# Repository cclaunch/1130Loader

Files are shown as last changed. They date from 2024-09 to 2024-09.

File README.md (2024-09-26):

# 1130Loader

This is a minor enhancement to an IBM 1130 that allows users to enter commands from a PC either directly or through a file, entering data words into core. This will be version 5 of the design, a significant change. 

Manually toggling in programs is a time consuming affair, flipping the 16 Console Entry Switches and pushing the Program Start button to enter each word sequentially. Every change in the area of core to be loaded requires that the address be set in those entry switches and the Load IAR button be pressed.

This device utilizes the cycle steal capability of the 1130, where peripheral controllers can read or write locations in memory by causing the CPU to pause while a memory cycle is used for the peripheral, then the CPU instruction processing continues. This is very similar to DMA on a microprocessor. 

When used with a terminal program that will send lines of a text file when it receives the prompt character from the loader, this allows files to be prepared to load into core of the 1130 in a rapid and reliable way. The format of the text file was chosen to match the simh based IBM 1130 Simulator memory dump format, thus programs can be tested on the simulator, dumped to files and loaded onto the physical 1130 system for execution. The format is to place each word as four ASCII characters represening the four hex digits. If the four digit line is prefixed by the command character @, the value is loaded into the 1130 IAR to set the location for subsequent memory words. If the line is prefixed by the command character Z it loads words of 0000 into as many locations as the four hex digits specify. If the command character prefix is =, the four digit value is saved and at the end of the loading, the IAR will be set to this value as the starting point for execution. Finally the command character # entered on a line by itself will toggle the loader to activation or deactivate it. Thus each simulator memory dump file needs to have a # line added at the front and at the end. 

To use the loader, connect a serial connection to the USB connector on the 1130 and open the terminal program. The 1130 must be stopped for this to runction, otherwise nothing special is needed. 

Physically the loader consists of an Arduino Mega 2560 and a custom shield that interfaces it to the IBM 1130. This is mounted on the logic gate B, connected to header boards on the gate which are then connected to individual backplane (board) pins using wirewrap. 

The code allows you to substitute different command characters and change the prompt character.

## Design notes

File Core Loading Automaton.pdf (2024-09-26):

# Core Loading Automaton

1 | Version 4

A tool I originally developed at the request of Peter Vaughan of The National Museum of Computing, this minor modification to an IBM 1130 will allow a PC based file of memory words to be loaded automatically into the core of an 1130.

A significant speedup was accomplished over previous versions by redesigning to use the cycle steal mechanism of the IBM 1130, analogous to Direct Memory Access (DMA) of microprocessor systems. This supported higher speed peripherals which used cycle stealing to fetch or store words into core memory without involving programs running on the CPU.

The device controller requests use of cycle stealing by raising the request line for the CS level it was assigned. When the CPU has finished a memory cycle, it grants the highest priority request a cycle steal and signals it was granted by raising the CS Level line.

The controller sets the bits of the data word and the memory address by pulling down the bits of the IO Data and Address bus to zero for each bit that has a 1 value. When the cycle steal clock reaches state X6, the request is dropped and the IO Data and Address lines are turned off by the controller. The end of the cycle steal is indicated by the dropping of the CS Level line.

My device is implemented as a shield sitting on an Arduino Mega 2560 to handle the conversation with a terminal or other program outside the IBM 1130. It watches the key CPU signals and sets the data, address and cycle steal request lines just as a device controller would do. Thus, it will trigger a cycle steal for a specific core address and store a given word there.

To simplify the design, it requires that the CPU be stopped before it will work. This ensures that no device controller is attempting cycle steals and that no other requests for memory access are taking place. It uses the highest priority cycle steal level (CS Level 0).

Sending a line over the serial line starting with # indicates the start of a session. The loader will ignore input until activated. Sending another # will end the session and inform the operator to resume normal 1130 operations. If core contents are saved from the IBM 1130 simulator, that file needs to have a line with # added at the front and bottom in order to use it with the loader.

When an address (hex word prefixed by @) is received, it sets up that address in the Arduino as the location for the next data word received When it receives a hex word without the prefix, it uses the saved address in the Arduino to load the data and increments the address afterwards so that the next data word goes into the next sequential location.

When an address prefixed by = is received, the code saves that address and then when the session is deactivated, it will remind the user to load that into the IAR so that the 1130 will fetch instructions from that address when Prog Start is pushed.

If a hex word is prefixed by Z then the hex value is a count for how many words of 0000 should be loaded into contiguous locations in 1130 core.

The loader communicates over a serial link on a USB cable, interpreting each line of text sent to it as four hex characters with some simple error checking. The line is converted to the 16 bit values for the data word to load.

The device uses open collector gates to connect selected pins on the 1130 to ground when that signal is asserted by the logic. Gates are connected to pins where we need to read CPU signals, passing them to the logic. Wire wrap is used to link the pins to a header on the shield.

We connect to the +12V power supply from the main 1130 distribution terminal block and use it to provide power to our loader device. The components on the shield regulates the raw supply down to 9V for powering the Arduino and to 5V to power the logic on the shield.

Software

The Arduino program loops listening to the serial port (USB link to PC) at 9600-N-8-1 setting. Command characters (#, =, @, or Z) are pulled off the line and handled first. It builds up a line of four characters, if longer it is an error and if shorter the input is ignored. The code skips any NL (x0A) or CR (x0D). It looks for exactly four characters that are valid hexadecimal - 0, 1, 2, 3, 4, 5, 6, 7, 8, 9, A, B, C, D, E, or F. The letters can be upper or lower case ASCII.

Once it has a good word, it sets the data value and address on its output pins and raises the request line to the shield via another output pin. It waits for the incoming Request Done signal on an input pin, then drops the data, address and request lines to end this cycle. Once it is done, we go back to give a prompt and accept the next word of entry from the terminal hooked to our USB cable. We also bump the saved memory address at the end of each cycle.

If the user enters an @ in the line with the four hex characters, we capture that as the new memory address we will output for the next data request.

This code is written for an Arduino Mega 2560 board. We need 32 output pins and 1 input pin, which excludes most of the smaller Arduino boards. The hardware that interfaces this to the IBM 1130 is contained on a shield, a small PCB that is mounted atop the Arduino.

The code and other design files is shared on Github to be available to any 1130 restorer wishing to use or modify this device.

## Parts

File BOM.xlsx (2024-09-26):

Part number | Value | Size | Vendor | vendor number
U1 | 74LS74 | 14SOIC | Digikey | 296-14899-1-ND
U2 | 74LS00 | 14SOIC | Digikey | 296-14873-1-ND
U3 | LM78L05 | S08 | Mouser | 926-LM78L05ACMX/NOPB
U6 | 74LS04 | 14SOIC | Digikey | 296-14875-1-ND
U7 | 74LS07 | 14SOIC | Digikey | 296-14877-1-ND
U8 | 74LS03 | 14SOIC | Digikey | 296-33951-5-ND
U9 | 74LS03 | 14SOIC | Digikey | 296-33951-5-ND
U10 | 74LS03 | 14SOIC | Digikey | 296-33951-5-ND
U11 | 74LS03 | 14SOIC | Digikey | 296-33951-5-ND
U12 | 74LS03 | 14SOIC | Digikey | 296-33951-5-ND
U13 | 74LS03 | 14SOIC | Digikey | 296-33951-5-ND
U14 | 74LS03 | 14SOIC | Digikey | 296-33951-5-ND
U15 | 74LS03 | 14SOIC | Digikey | 296-33951-5-ND
U17 | LM78L12 | S08 | Digikey | 296-LM78L12ACMX/NOPBCT-ND
U19 | 74LS04 | 14SOIC | Digikey | 296-14875-1-ND
U20 | 74LS74 | 14SOIC | Digikey | 296-14899-1-ND
R1 | 5K | 0805 | Digikey | 541-CRCW08055K00JNTACT-ND
R2 | 5K | 0805 | Digikey | 541-CRCW08055K00JNTACT-ND
R3 | 5K | 0805 | Digikey | 541-CRCW08055K00JNTACT-ND
J1 | 1x8 | 2.54mm | Digikey | 2057-PH1-08-UA-ND
J2 | 1x16 | 2.54mm | Digikey | 2057-PH1-16-UA-ND
J3 | 1x16 | 2.54mm | Digikey | 2057-PH1-16-UA-ND
J4 | 1x2 |  | Digikey | 277-1236-ND
C1 | 100nf | 0805 | Digikey | 478-KGM21NR71H104KTCT-ND
C2 | 100nf | 0805 | Digikey | 478-KGM21NR71H104KTCT-ND
C3 | 100nf | 0805 | Digikey | 478-KGM21NR71H104KTCT-ND
C4 | 100nf | 0805 | Digikey | 478-KGM21NR71H104KTCT-ND
C5 | 100nf | 0805 | Digikey | 478-KGM21NR71H104KTCT-ND
C6 | 100nf | 0805 | Digikey | 478-KGM21NR71H104KTCT-ND
C7 | 100nf | 0805 | Digikey | 478-KGM21NR71H104KTCT-ND
C8 | 100nf | 0805 | Digikey | 478-KGM21NR71H104KTCT-ND
C9 | 100nf | 0805 | Digikey | 478-KGM21NR71H104KTCT-ND
C11 | 100nf | 0805 | Digikey | 478-KGM21NR71H104KTCT-ND
C12 | 100nf | 0805 | Digikey | 478-KGM21NR71H104KTCT-ND
C13 | 100nf | 0805 | Digikey | 478-KGM21NR71H104KTCT-ND
C14 | 100nf | 0805 | Digikey | 478-KGM21NR71H104KTCT-ND
C15 | 100nf | 0805 | Digikey | 478-KGM21NR71H104KTCT-ND
C16 | 100nf | 0805 | Digikey | 478-KGM21NR71H104KTCT-ND
C17 | 330nf | 0805 | Digikey | 490-14413-1-ND
C18 | 100nf | 0805 | Digikey | 478-KGM21NR71H104KTCT-ND
C19 | 330nf | 0805 | Digikey | 490-14413-1-ND
C20 | 100nf | 0805 | Digikey | 478-KGM21NR71H104KTCT-ND
A1 | 1x10 | 2.54mm | Digikey | 2057-PH1-10-UA-ND
A2 | 1x8 | 2.54mm | Digikey | 2057-PH1-08-UA-ND
A3 | 1x8 | 2.54mm | Digikey | 2057-PH1-08-UA-ND
A4 | 2x20 | 2.54mm | Digikey | 2057-PH2-20-UA-ND
A5 | 1x8 | 2.54mm | Digikey | 2057-PH1-08-UA-ND
A6 | 1x8 | 2.54mm | Digikey | 2057-PH1-08-UA-ND
A7 | 1x8 | 2.54mm | Digikey | 2057-PH1-08-UA-ND
P1 | 1x8 | 2.54mm | Mouser | 200-IDSS08D2000GR
P2 | 1x16 | 2.54mm | Mouser | 200-IDSS16D2000
P3 | 1x16 | 2.54mm | Mouser | 200-IDSS16D2000

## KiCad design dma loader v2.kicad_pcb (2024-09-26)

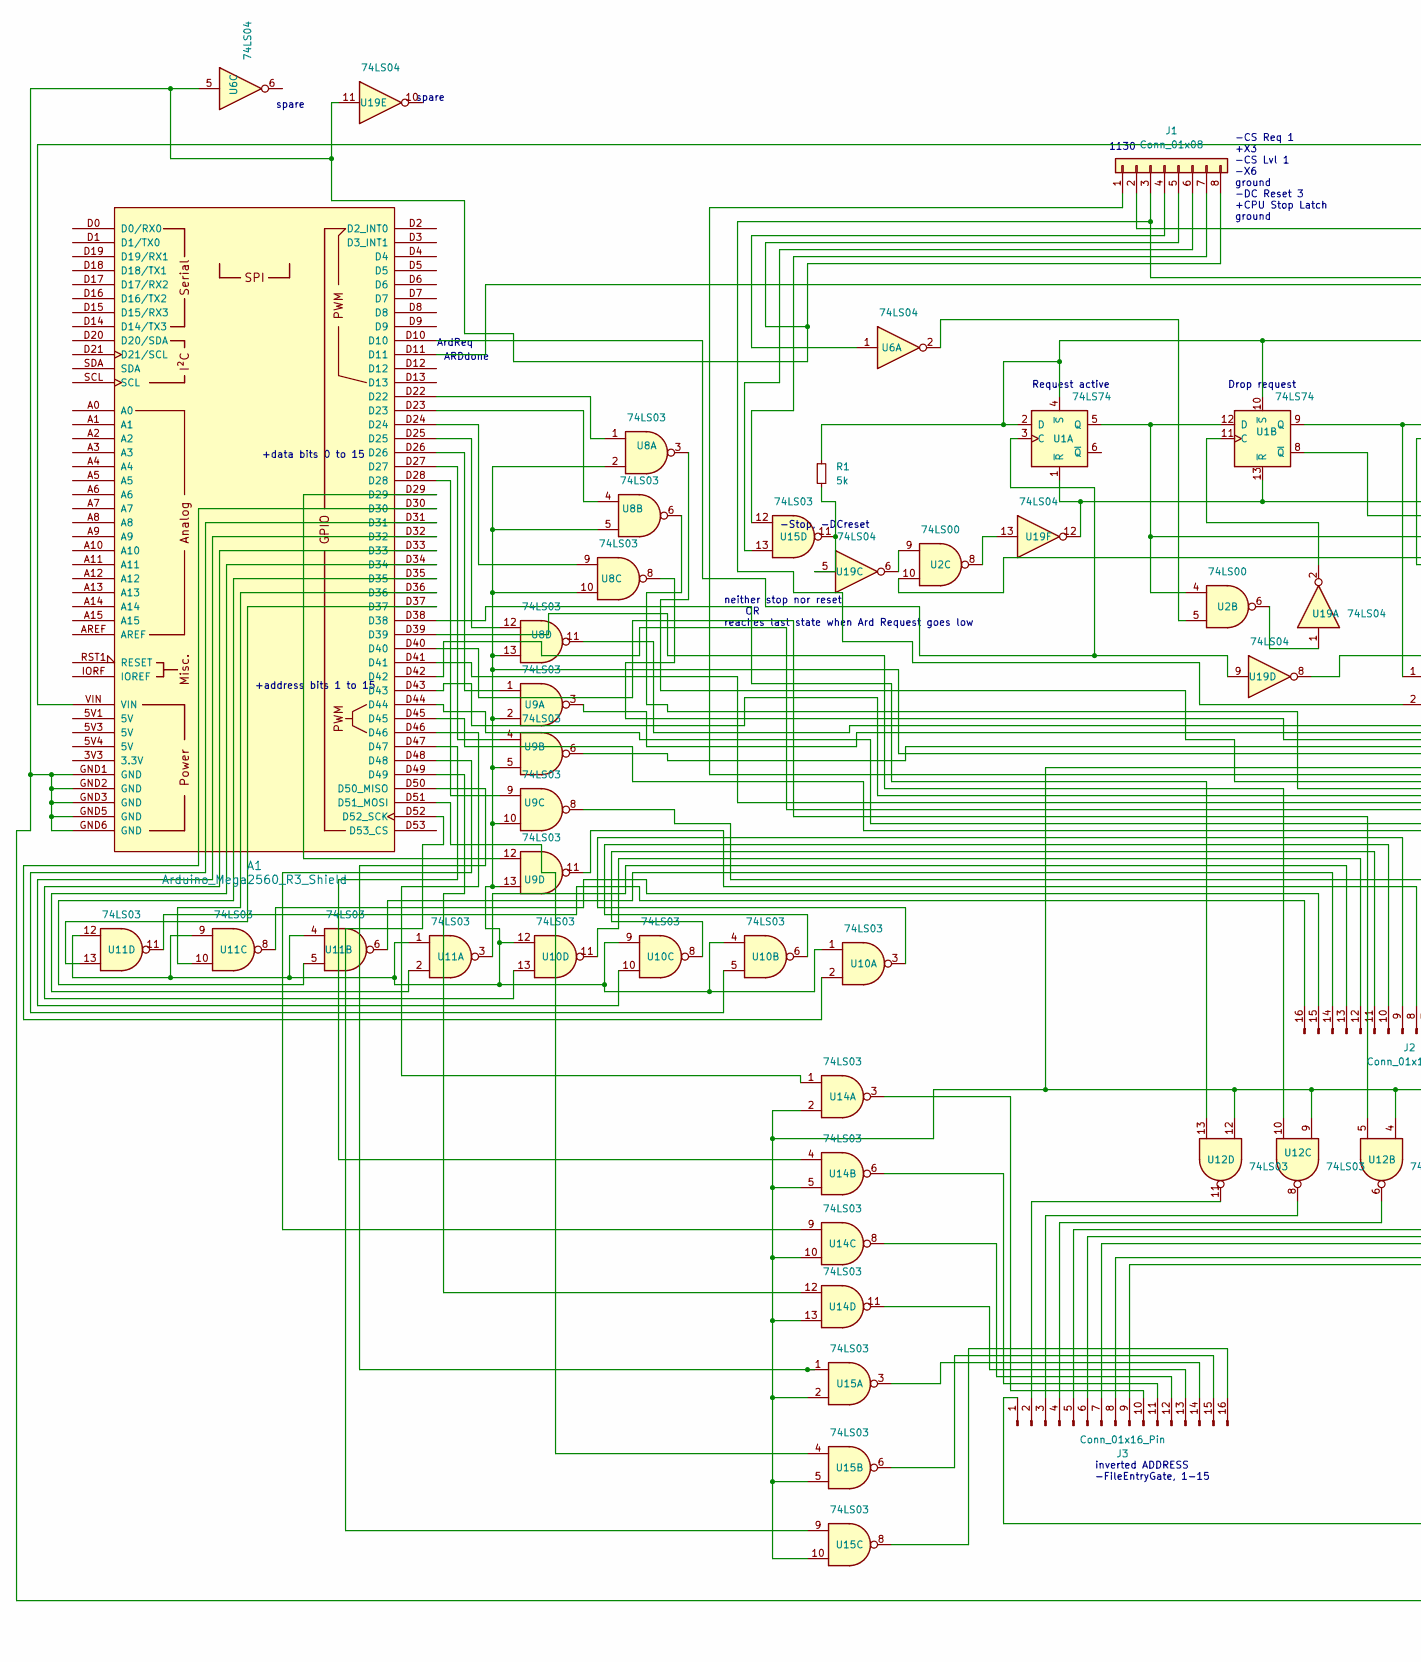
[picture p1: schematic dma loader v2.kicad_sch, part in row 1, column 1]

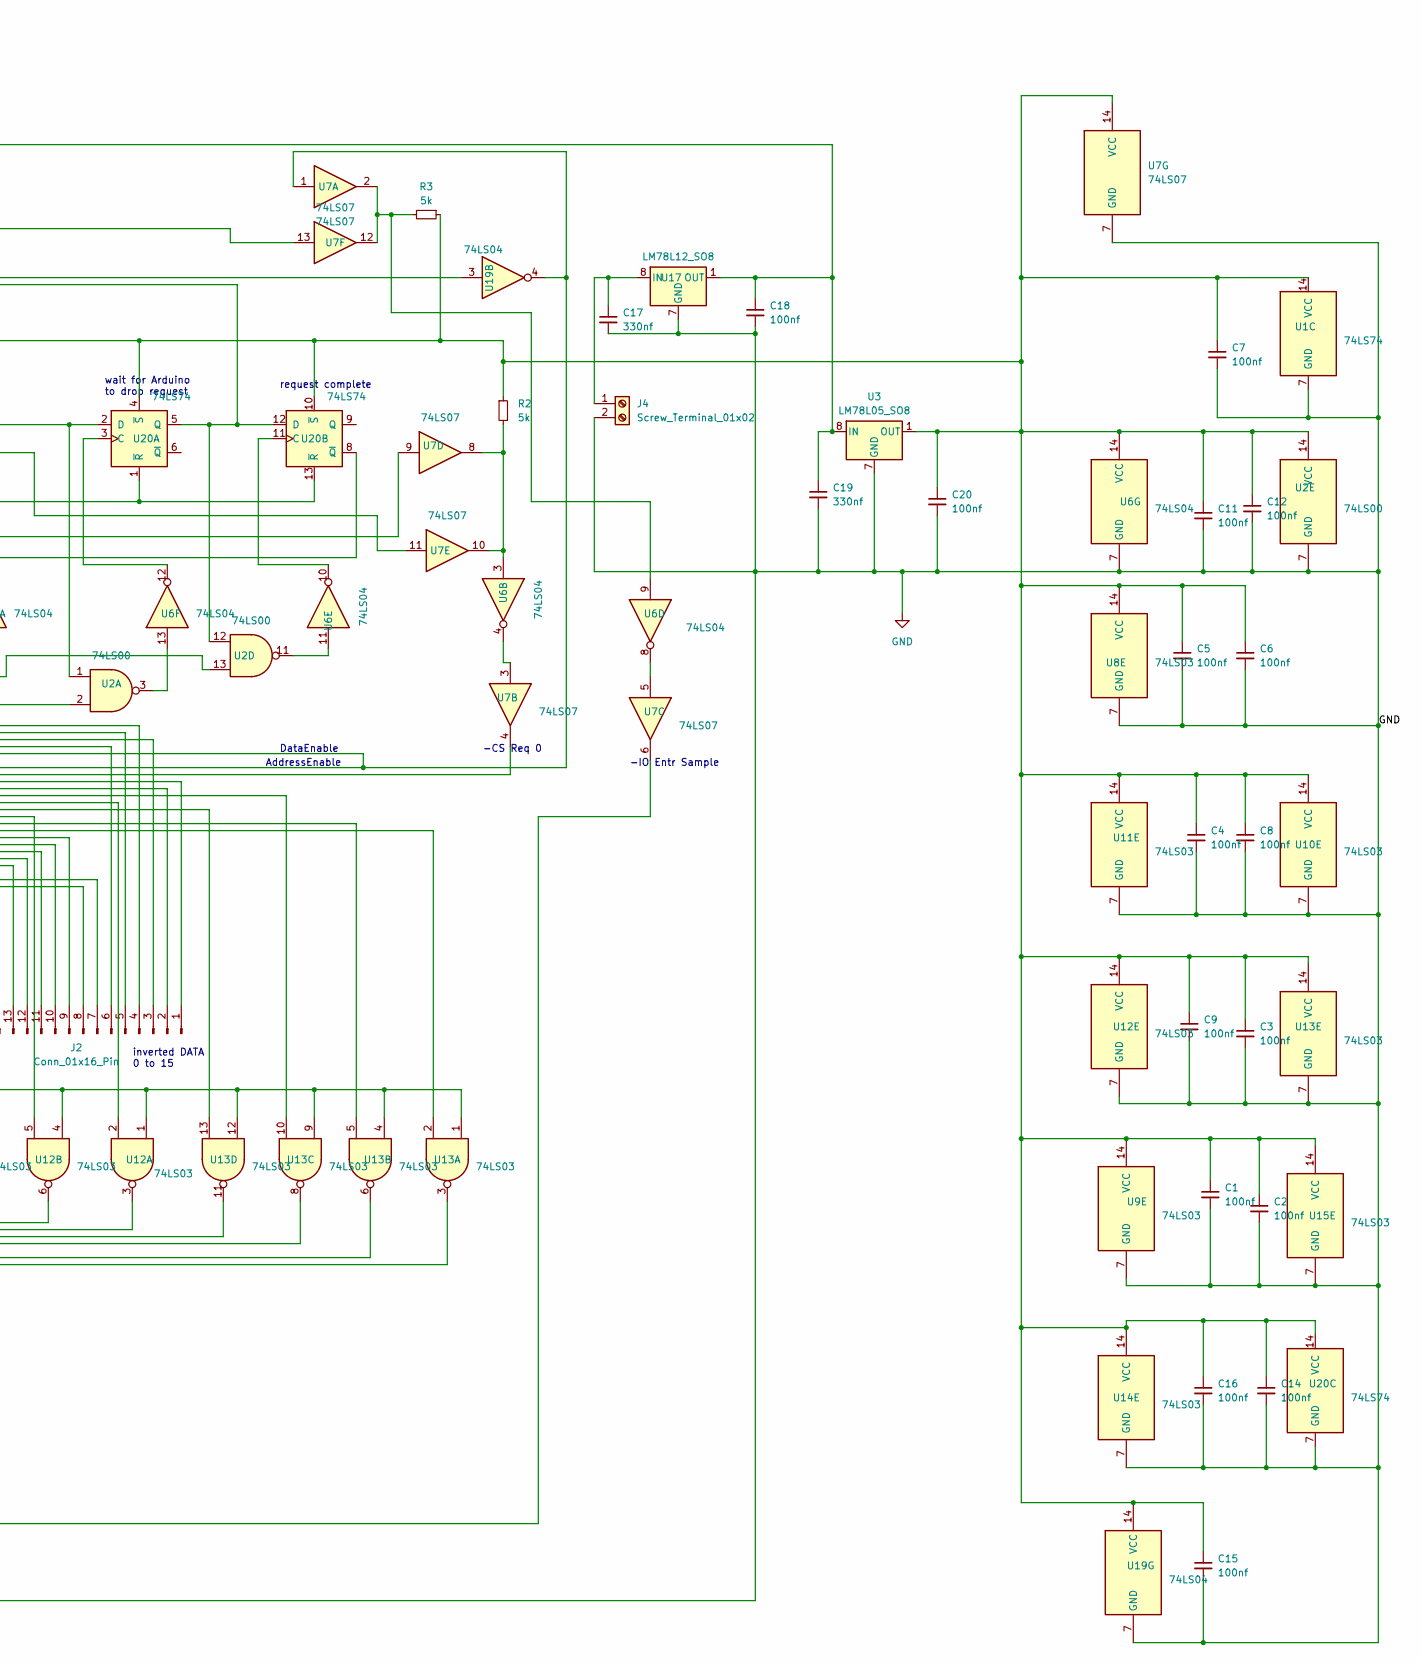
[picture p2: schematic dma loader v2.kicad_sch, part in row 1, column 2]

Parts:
A1: Arduino_Mega2560_R3_Shield
C1, C2, C3, C4, C5, C6, C7, C8, C9, C11, C12, C14, C15, C16, C18, C20: 100nf; C_0805_2012Metric_Pad1.18x1.45mm_HandSolder
C17, C19: 330nf; C_0805_2012Metric_Pad1.18x1.45mm_HandSolder
J1: Conn_01x08; PinHeader_1x08_P2.54mm_Vertical
J2, J3: Conn_01x16_Pin; PinHeader_1x16_P2.54mm_Vertical
J4: Screw_Terminal_01x02; PhoenixContact_MSTBA_2,5_2-G_1x02_P5.00mm_Horizontal
R1, R2, R3: 5k; R_0805_2012Metric_Pad1.20x1.40mm_HandSolder
U1, U20: 74LS74; SOIC-14_3.9x8.7mm_P1.27mm
U2: 74LS00; SOIC-14_3.9x8.7mm_P1.27mm
U3: LM78L05_SO8; SOIC-8_3.9x4.9mm_P1.27mm
U6, U19: 74LS04; SOIC-14_3.9x8.7mm_P1.27mm
U7: 74LS07; SOIC-14_3.9x8.7mm_P1.27mm
U8, U9, U10, U11, U12, U13, U14, U15: 74LS03; SOIC-14_3.9x8.7mm_P1.27mm
U17: LM78L12_SO8; SOIC-8_3.9x4.9mm_P1.27mm

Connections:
GND: A1.GND1 (GND), A1.GND2 (GND), A1.GND3 (GND), A1.GND5 (GND), A1.GND6 (GND), C1.2, C2.2, C3.2, C4.2, C5.2, C6.2, C7.2, C8.2, C9.2, C11.2, C12.2, C14.2, C15.2, C16.2, C17.2, C18.2, C19.2, C20.2, J1.5, J1.8, J4.2, U1.7 (GND), U2.7 (GND), U3.2 (GND), U3.3 (GND), U3.6 (GND), U3.7 (GND), U6.5, U6.7 (GND), U7.7 (GND), U8.7 (GND), U9.7 (GND), U10.7 (GND), U11.7 (GND), U12.7 (GND), U13.7 (GND), U14.7 (GND), U15.7 (GND), U17.2 (GND), U17.3 (GND), U17.6 (GND), U17.7 (GND), U19.7 (GND), U19.11, U20.7 (GND)
unnamed: A1.D50 (D50_MISO), U15.1
unnamed: A1.D51 (D51_MOSI), U15.4
unnamed: A1.D52 (D52_SCK), U15.9
unnamed: A1.D22, U8.1
unnamed: A1.D23, U8.4
unnamed: A1.D24, U8.9
unnamed: A1.D25, U8.12
unnamed: A1.D26, U9.1
unnamed: A1.D27, U9.4
unnamed: A1.D28, U9.9
unnamed: A1.D29, U9.12
unnamed: A1.D30, U10.2
unnamed: A1.D31, U10.5
unnamed: A1.D32, U10.10
unnamed: A1.D33, U10.13
unnamed: A1.D34, U11.2
unnamed: A1.D35, U11.5
unnamed: A1.D36, U11.10
unnamed: A1.D37, U11.13
unnamed: A1.D38, U12.13
unnamed: A1.D39, U12.10
unnamed: A1.D40, U12.5
unnamed: A1.D41, U12.2
unnamed: A1.D42, U13.13
unnamed: A1.D43, U13.10
unnamed: A1.D44, U13.5
unnamed: A1.D45, U13.2
unnamed: A1.D46, U14.1
unnamed: A1.D47, U14.4
unnamed: A1.D48, U14.9
unnamed: A1.D49, U14.12
unnamed: J1.1, U7.4
unnamed: J1.2, U7.13
unnamed: J1.3, U2.2, U19.3
unnamed: J1.4, U6.1
unnamed: J1.6, U15.13
unnamed: J1.7, U15.12
unnamed: J2.1, U8.3
unnamed: J2.2, U8.6
unnamed: J2.3, U8.8
unnamed: J2.4, U8.11
unnamed: J2.5, U9.3
unnamed: J2.6, U9.6
unnamed: J2.7, U9.8
unnamed: J2.8, U9.11
unnamed: J2.9, U10.3
unnamed: J2.10, U10.6
unnamed: J2.11, U10.8
unnamed: J2.12, U10.11
unnamed: J2.13, U11.3
unnamed: J2.14, U11.6
unnamed: J2.15, U11.8
unnamed: J2.16, U11.11
unnamed: J3.1, U7.6
unnamed: J3.2, U12.11
unnamed: J3.3, U12.8
unnamed: J3.4, U12.6
unnamed: J3.5, U12.3
unnamed: J3.6, U13.11
unnamed: J3.7, U13.8
unnamed: J3.8, U13.6
unnamed: J3.9, U13.3
unnamed: J3.10, U14.3
unnamed: J3.11, U14.6
unnamed: J3.12, U14.8
unnamed: J3.13, U14.11
unnamed: J3.14, U15.3
unnamed: J3.15, U15.6
unnamed: J3.16, U15.8
unnamed: C17.1, J4.1, U17.8 (IN)
unnamed: R1.2, U15.11, U19.5
unnamed: R2.2, U6.3, U7.8, U7.10
unnamed: R3.2, U6.9, U7.2, U7.12
unnamed: A1.D10, U1.3 (C), U19.9
unnamed: U1.5 (Q), U1.12 (D), U2.4, U7.9
unnamed: U1.1 (~R), U1.13 (~R), U19.12, U20.1 (~R), U20.13 (~R)
unnamed: U1.11 (C), U19.2
unnamed: U1.9 (Q), U2.1, U20.2 (D)
unnamed: U1.8 (~Q), U7.11
unnamed: U2.3, U6.13
unnamed: U2.5, U6.2
unnamed: U2.11, U6.11
unnamed: U6.4, U7.3
unnamed: U6.8, U7.5
unnamed: U7.1, U8.2, U8.5, U8.10, U8.13, U9.2, U9.5, U9.10, U9.13, U10.1, U10.4, U10.9, U10.12, U11.1, U11.4, U11.9, U11.12, U12.1, U12.4, U12.9, U12.12, U13.1, U13.4, U13.9, U13.12, U14.2, U14.5, U14.10, U14.13, U15.2, U15.5, U15.10, U19.4
unnamed: C1.1, C2.1, C3.1, C4.1, C5.1, C6.1, C7.1, C8.1, C9.1, C11.1, C12.1, C14.1, C15.1, C16.1, C20.1, R1.1, R2.1, R3.1, U1.2 (D), U1.4 (~S), U1.10 (~S), U1.14 (VCC), U2.14 (VCC), U3.1 (OUT), U6.14 (VCC), U7.14 (VCC), U8.14 (VCC), U9.14 (VCC), U10.14 (VCC), U11.14 (VCC), U12.14 (VCC), U13.14 (VCC), U14.14 (VCC), U15.14 (VCC), U19.14 (VCC), U20.4 (~S), U20.10 (~S), U20.14 (VCC)
unnamed: A1.VIN, C18.1, C19.1, U3.8 (IN), U17.1 (OUT)
unnamed: U2.6, U19.1
unnamed: U2.9, U19.6
unnamed: U2.13, U19.8
unnamed: U2.8, U19.13
unnamed: U6.12, U20.3 (C)
unnamed: A1.D11, U2.12, U20.5 (Q), U20.12 (D)
unnamed: U6.10, U20.11 (C)
unnamed: U2.10, U20.8 (~Q)

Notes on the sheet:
+data bits 0 to 15
-CS Req 0
-IO Entr Sample
-Stop, -DCreset
spare
neither stop nor reset OR reaches last state when Ard Request goes low
ARDdone
Request active
1130
AddressEnable
-CS Req 1 +X3 -CS Lvl 1 -X6 ground -DC Reset 3 +CPU Stop Latch ground
+address bits 1 to 15
inverted DATA 0 to 15
request complete
ArdReq
wait for Arduino to drop request
DataEnable
inverted ADDRESS -FileEntryGate, 1-15
Drop request

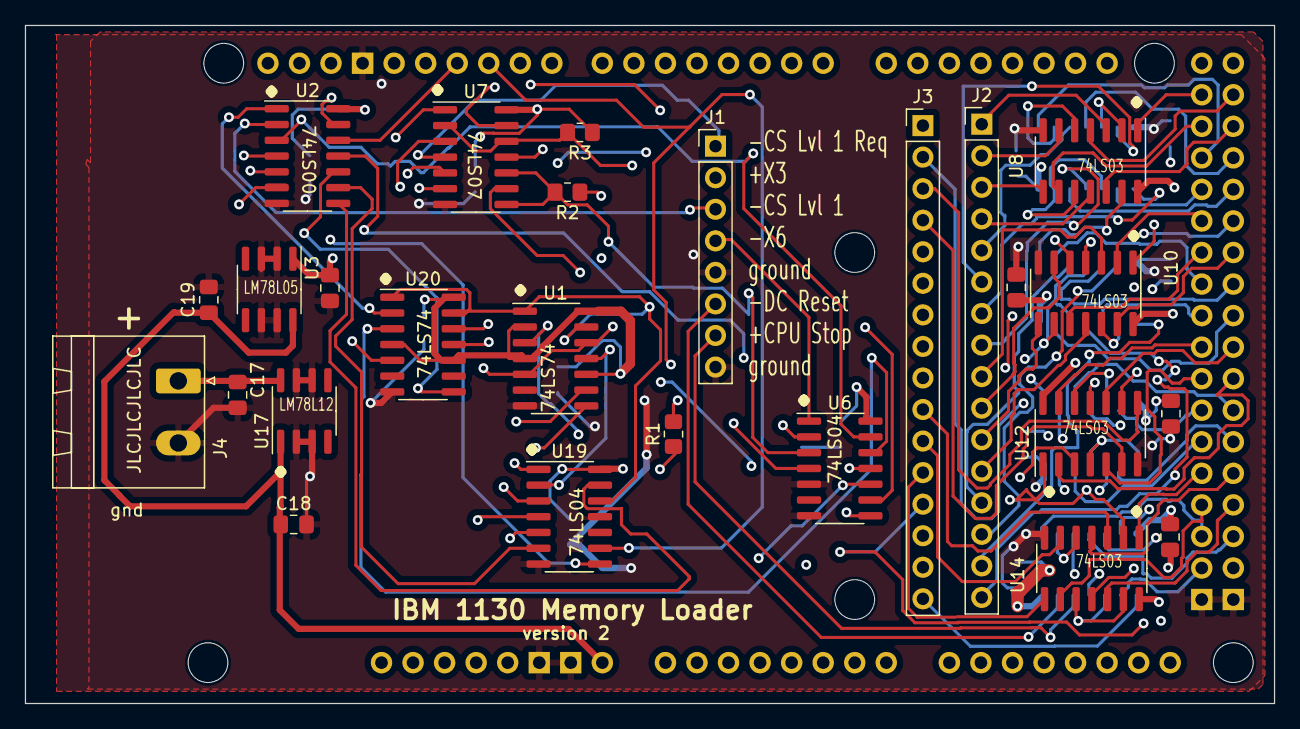
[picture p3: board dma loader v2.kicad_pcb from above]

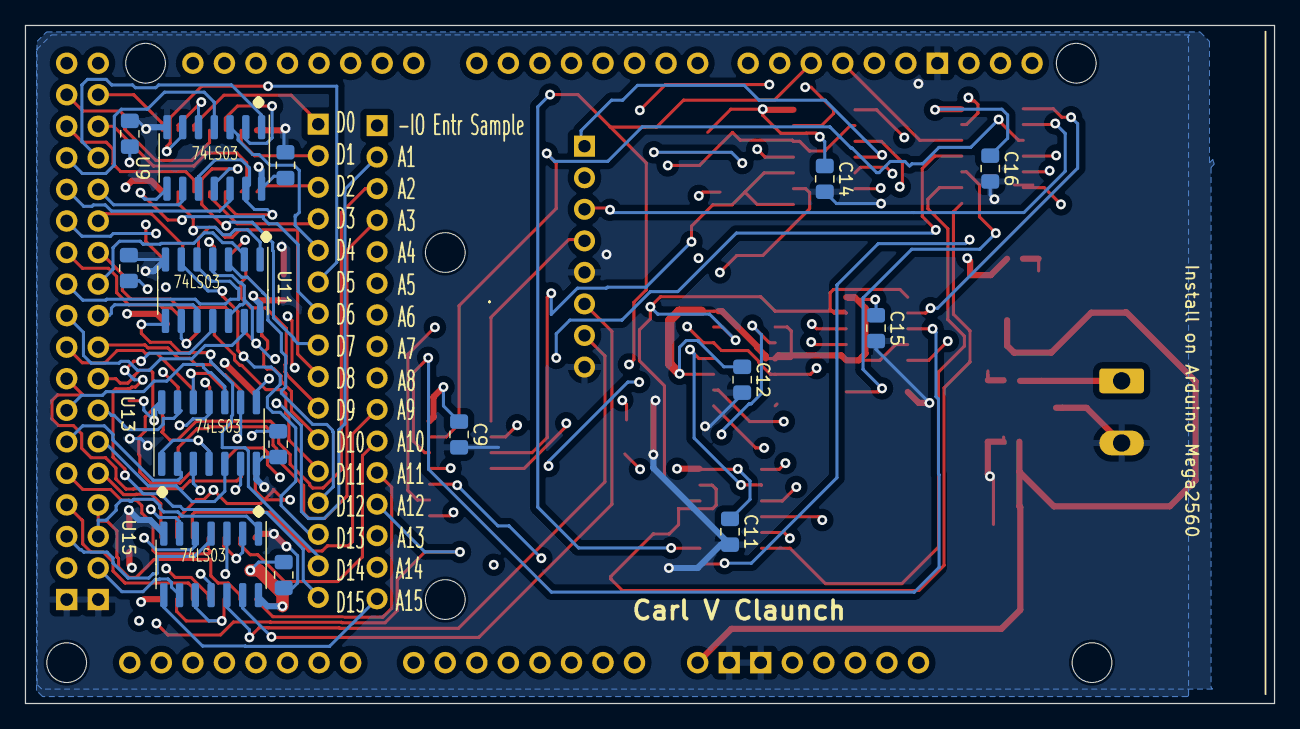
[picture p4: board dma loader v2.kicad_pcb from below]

Board: 4 copper layers, 100.6 x 54.6 mm, 42 parts (15 on the bottom side), 96 nets.

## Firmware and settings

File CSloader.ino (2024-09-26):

// ============================================================================================
//
//   MEMORY LOADER FOR IBM 1130     Version 5
//
// ============================================================================================
//
//  A shield on the Arduino has a state machine and gates that interface with an IBM 1130
//  to cause the CPU to do a cycle steal, which is IBM's term for what is more commonly
//  known as Direct Memory Access (DMA)
//
//  The Arduino sets and address on 15 pins and a data word on another 16 pins, then
//  sets the 'ardreq' pin high to trigger the shield's state machine.
//  
//  The shield requires that the 1130 be in the stopped state, not executing instructions
//  as that simplified the design substantially. It will also reset when the RESET button
//  of the 1130 is pushed (or at power on time)
//
//  The state machine, once triggered, will raise the request line to the CPU asking
//  for a cycle steal to be performed. As the 1130 enters cycle steal mode, the state 
//  machine waits until the machine reaches the X6 clock state, where it drop the
//  cycle steal request. It then waits for CS Level 0 tto drop then it raises the
//  'arddone' pin back to the Arduino. The Arduino should drop its request for the 
//  cycle steal, after which the state machine goes back to idle waiting for the
//  next request.
//
//  Since a cycle steal occurs in one memory cycle of the 1130, either 3.6 or 2.5
//  microseconds, it is extremely fast. The rate at which lines are sent over the 
//  USB cable from the remote PC/Mac/Terminal/etc will be the pacing factor in 
//  how fast memory can be loaded, but at the default 9600 baud it should load
//  around 120 words per second, thus each 4K of memory loads in about half
//  a minute. Each address loading command requires 1/120 of a second but
//  commands to zero a block of data can run much faster.
//
//  The largest possible 1130 configuration (32K) would require
//  four to five minutes to load at the default 9600 baud rate.

//  Boosting the serial port rate on both Arduino and terminal/PC to
//  115,200 baud will increase that speed of loading 4K to a bit over 2 seconds
//  and thus a 32K 1130 configuration would load in under a half minute.
//   

// This section contains values to modify to configure this to your own choice of 
// command characters and any changes to Arduino Mega 2560 pin assignments

#define ardreq    10          // request for a cycle steal sent to the shield
#define arddone   11          // response from shield when a cycle is complete

#define A1        38          // bit 1 of the address to store the data
#define A2        39          // bit 2 of the address to store the data
#define A3        40          // bit 3 of the address to store the data
#define A4        41          // bit 4 of the address to store the data
#define A5        42          // bit 5 of the address to store the data
#define A6        43          // bit 6 of the address to store the data
#define A7        44          // bit 7 of the address to store the data
#define A8        45          // bit 8 of the address to store the data
#define A9        46          // bit 9 of the address to store the data
#define A10       47          // bit 10 of the address to store the data
#define A11       48          // bit 11 of the address to store the data
#define A12       49          // bit 12 of the address to store the data
#define A13       50          // bit 13 of the address to store the data
#define A14       51          // bit 14 of the address to store the data
#define A15       52          // bit 15 of the address to store the data

#define D0        22          // bit 0 of the data value to store
#define D1        23          // bit 1 of the data value to store
#define D2        24          // bit 2 of the data value to store
#define D3        25          // bit 3 of the data value to store
#define D4        26          // bit 4 of the data value to store
#define D5        27          // bit 5 of the data value to store
#define D6        28          // bit 6 of the data value to store
#define D7        29          // bit 7 of the data value to store
#define D8        30          // bit 8 of the data value to store
#define D9        31          // bit 9 of the data value to store
#define D10       32          // bit 10 of the data value to store
#define D11       33          // bit 11 of the data value to store
#define D12       34          // bit 12 of the data value to store
#define D13       35          // bit 13 of the data value to store
#define D14       36          // bit 14 of the data value to store
#define D15       37          // bit 15 of the data value to store

#define BITON     HIGH
#define BITOFF    LOW

#define COMMRATE  9600        // can be up to 115200 or more depending on accuracy of sending UART clock

// change these to select alternate command characters
// the default characters match output of IBM 1130 Simulator at ibm1130.org
#define LOADCHAR '@'
#define ACTIVATECHAR '#'
#define STARTCHAR '='
#define ZEROCHAR 'Z'

// change this to emit a different prompt character to send the next line of file
#define PROMPT '>'

// global variables
int load = 0;
int deact = 0;
int act = 0;
int saved = 0;
int activated = 0;
int zero = 0;
char newword[5] = {0,0,0,0,0};
char saveaddr[5] = {0,0,0,0,0};
long currentaddress;
long outputdata;

// this initializes the program at startup
void setup() {

  pinMode(arddone, INPUT);
  pinMode(ardreq, OUTPUT);
//  digitalWrite(ardreq, LOW);      this is default behavior when pin set to output

  pinMode(D0, OUTPUT);
  pinMode(D1, OUTPUT);
  pinMode(D2, OUTPUT);
  pinMode(D3, OUTPUT);
  pinMode(D4, OUTPUT);
  pinMode(D5, OUTPUT);
  pinMode(D6, OUTPUT);
  pinMode(D7, OUTPUT);
  pinMode(D8, OUTPUT);
  pinMode(D9, OUTPUT);
  pinMode(D10, OUTPUT);
  pinMode(D11, OUTPUT);
  pinMode(D12, OUTPUT);
  pinMode(D13, OUTPUT);
  pinMode(D14, OUTPUT);
  pinMode(D15, OUTPUT);
  digitalWrite(D0,LOW);
  digitalWrite(D1,LOW);
  digitalWrite(D2,LOW);
  digitalWrite(D3,LOW);
  digitalWrite(D4,LOW);
  digitalWrite(D5,LOW);
  digitalWrite(D6,LOW);
  digitalWrite(D7,LOW);
  digitalWrite(D8,LOW);
  digitalWrite(D9,LOW);
  digitalWrite(D10,LOW);
  digitalWrite(D11,LOW);
  digitalWrite(D12,LOW);
  digitalWrite(D13,LOW);
  digitalWrite(D14,LOW);
  digitalWrite(D15,LOW);

  pinMode(A1, OUTPUT);
  pinMode(A2, OUTPUT);
  pinMode(A3, OUTPUT);
  pinMode(A4, OUTPUT);
  pinMode(A5, OUTPUT);
  pinMode(A6, OUTPUT);
  pinMode(A7, OUTPUT);
  pinMode(A8, OUTPUT);
  pinMode(A9, OUTPUT);
  pinMode(A10, OUTPUT);
  pinMode(A11, OUTPUT);
  pinMode(A12, OUTPUT);
  pinMode(A13, OUTPUT);
  pinMode(A14, OUTPUT);
  pinMode(A15, OUTPUT);
  digitalWrite(A1,LOW);
  digitalWrite(A2,LOW);
  digitalWrite(A3,LOW);
  digitalWrite(A4,LOW);
  digitalWrite(A5,LOW);
  digitalWrite(A6,LOW);
  digitalWrite(A7,LOW);
  digitalWrite(A8,LOW);
  digitalWrite(A9,LOW);
  digitalWrite(A10,LOW);
  digitalWrite(A11,LOW);
  digitalWrite(A12,LOW);
  digitalWrite(A13,LOW);
  digitalWrite(A14,LOW);
  digitalWrite(A15,LOW);

  // Start up our link with the terminal user
  // this remains active anytime the 1130 is running
  // with no reset upon connection due to capacitor
  // across the reset and ground pins
  Serial.begin(COMMRATE);
}

// tests an input word of four characters to determine if
// it is a valid hexadecimal value, returning true or false
bool checkword(char * theword) {
  int i;
  for (i = 0; i < 4; i++) {
    if (isHexadecimalDigit(theword[i]) == false) {
      return false;
    }
  }
  return true;
}

// function will convert the four ASCII characters to the hexadecimal value
// of that address or data, returning the value to the main routine
long grabvalue(char* theword) {
  int i;
  char bits;
  long anAddress = 0;
    
  for (i=0; i<4; i++) {
    bits = theword[i];  // grab each hex character from input
    bits -= 48;         // ASCII digits are 48 to 57
    if (bits > 16) {
      bits -= 39;       // upper case characters A-F are 97-102 so 97 - 48 - 39 = 10
    }
    if (i == 0) {
      if (bitRead(bits,3) == 1) {
        anAddress += 32768;
      }
      if (bitRead(bits,2) == 1) {
        anAddress += 16384;
      }
      if (bitRead(bits,1) == 1) {
        anAddress += 8192;
      }
      if (bitRead(bits,0) == 1) {
        anAddress += 4096;
      }
    } else if (i == 1) {
      if (bitRead(bits,3) == 1) {
        anAddress += 2048;
      }
      if (bitRead(bits,2) == 1) {
        anAddress += 1024;
      }
      if (bitRead(bits,1) == 1) {
        anAddress += 512;
      }
      if (bitRead(bits,0) == 1) {
        anAddress += 256;
      }
    } else if (i == 2) {
      if (bitRead(bits,3) == 1) {
        anAddress += 128;
      }
      if (bitRead(bits,2) == 1) {
        anAddress += 64;
      }
      if (bitRead(bits,1) == 1) {
        anAddress += 32;
      }
      if (bitRead(bits,0) == 1) {
        anAddress += 16;
      }
    } else if (i == 3) {
      if (bitRead(bits,3) == 1) {
        anAddress += 8;
      }
      if (bitRead(bits,2) == 1) {
        anAddress += 4;
      }
      if (bitRead(bits,1) == 1) {
        anAddress += 2;
      }
      if (bitRead(bits,0) == 1) {
        anAddress += 1;
      }
    } 
  }
  
  return anAddress;
}

// this sets up the address and data pins on the shield then raises a request line
// returns once the cycle steal is complete as verified by arddone signal
void store2memory() {

  // first set up address for cycle steal
  if (bitRead(currentaddress,14)== 1) {
    digitalWrite(A1,BITON);
  } else {
    digitalWrite(A1,BITOFF);
  }
  if (bitRead(currentaddress,13)== 1) {
    digitalWrite(A2,BITON);
  } else {
    digitalWrite(A2,BITOFF);
  }
  if (bitRead(currentaddress,12)== 1) {
    digitalWrite(A3,BITON);
  } else {
    digitalWrite(A3,BITOFF);
  }
  if (bitRead(currentaddress,11)== 1) {
    digitalWrite(A4,BITON);
  } else {
    digitalWrite(A4,BITOFF);
  }
  if (bitRead(currentaddress,10)== 1) {
    digitalWrite(A5,BITON);
  } else {
    digitalWrite(A5,BITOFF);
  }
  if (bitRead(currentaddress,9)== 1) {
    digitalWrite(A6,BITON);
  } else {
    digitalWrite(A6,BITOFF);
  }
  if (bitRead(currentaddress,8)== 1) {
    digitalWrite(A7,BITON);
  } else {
    digitalWrite(A7,BITOFF);
  }
  if (bitRead(currentaddress,7)== 1) {
    digitalWrite(A8,BITON);
  } else {
    digitalWrite(A8,BITOFF);
  }
  if (bitRead(currentaddress,6)== 1) {
    digitalWrite(A9,BITON);
  } else {
    digitalWrite(A9,BITOFF);
  }
  if (bitRead(currentaddress,5)== 1) {
    digitalWrite(A10,BITON);
  } else {
    digitalWrite(A10,BITOFF);
  }
  if (bitRead(currentaddress,4)== 1) {
    digitalWrite(A11,BITON);
  } else {
    digitalWrite(A11,BITOFF);
  }
  if (bitRead(currentaddress,3)== 1) {
    digitalWrite(A12,BITON);
  } else {
    digitalWrite(A12,BITOFF);
  }
  if (bitRead(currentaddress,2)== 1) {
    digitalWrite(A13,BITON);
  } else {
    digitalWrite(A13,BITOFF);
  }
  if (bitRead(currentaddress,1)== 1) {
    digitalWrite(A14,BITON);
  } else {
    digitalWrite(A14,BITOFF);
  }
  if (bitRead(currentaddress,0)== 1) {
    digitalWrite(A15,BITON);
  } else {
    digitalWrite(A15,BITOFF);
  }

  // now set up data word for cycle steal
  if (bitRead(outputdata,15) == 1) {
    digitalWrite(D0, BITON); 
  } else {
    digitalWrite(D0, BITOFF);
  }
  if (bitRead(outputdata,14) == 1) {
    digitalWrite(D1, BITON); 
  } else {
    digitalWrite(D1, BITOFF);
  }
  if (bitRead(outputdata,13) == 1) {
    digitalWrite(D2, BITON); 
  } else {
    digitalWrite(D2, BITOFF);
  }
  if (bitRead(outputdata,12) == 1) {
    digitalWrite(D3, BITON); 
  } else {
    digitalWrite(D3, BITOFF);
  }
  if (bitRead(outputdata,11) == 1) {
    digitalWrite(D4, BITON); 
  } else {
    digitalWrite(D4, BITOFF);
  }
  if (bitRead(outputdata,10) == 1) {
    digitalWrite(D5, BITON); 
  } else {
    digitalWrite(D5, BITOFF);
  }
  if (bitRead(outputdata,9) == 1) {
    digitalWrite(D6, BITON); 
  } else {
    digitalWrite(D6, BITOFF);
  }
  if (bitRead(outputdata,8) == 1) {
    digitalWrite(D7, BITON); 
  } else {
    digitalWrite(D7, BITOFF);
  }
  if (bitRead(outputdata,7) == 1) {
    digitalWrite(D8, BITON); 
  } else {
    digitalWrite(D8, BITOFF);
  }
  if (bitRead(outputdata,6) == 1) {
    digitalWrite(D9, BITON); 
  } else {
    digitalWrite(D9, BITOFF);
  }
  if (bitRead(outputdata,5) == 1) {
    digitalWrite(D10, BITON); 
  } else {
    digitalWrite(D10, BITOFF);
  }
  if (bitRead(outputdata,4) == 1) {
    digitalWrite(D11, BITON); 
  } else {
    digitalWrite(D11, BITOFF);
  }
  if (bitRead(outputdata,3) == 1) {
    digitalWrite(D12, BITON); 
  } else {
    digitalWrite(D12, BITOFF);
  }
  if (bitRead(outputdata,2) == 1) {
    digitalWrite(D13, BITON); 
  } else {
    digitalWrite(D13, BITOFF);
  }
  if (bitRead(outputdata,1) == 1) {
    digitalWrite(D14, BITON); 
  } else {
    digitalWrite(D14, BITOFF);
  }
  if (bitRead(outputdata,0) == 1) {
    digitalWrite(D15, BITON); 
  } else {
    digitalWrite(D15, BITOFF);
  }     
 
  //  request cycle steal to be performed by shield
  digitalWrite(ardreq, HIGH);

  // now spin waiting until the operation completes
  while (digitalRead(arddone) == 0);

  // drop request and go away
  digitalWrite(ardreq, LOW);
  return;
}

// main loop run continuously by the Arduino
void loop() {
  int incomingchar = 0;
  int pointer = 0;
  int times = 1;
  long returnvalue;

  // first loop will collect inut from the serial connection to 
  // detect command characters and to assemble the four character
  // hex number that is an address, data or count
  Serial.println(PROMPT);

  
  while (1) {
    if (Serial.available() > 0) {
      incomingchar = Serial.read();
      if (isAlpha(incomingchar)) incomingchar = toupper(incomingchar);
      if ((incomingchar == '\n') or (incomingchar == '\r')) {
        if ((act == 1) or (deact) == 1) {      // activation character handled immediately, don't collect four characters
          pointer = 0;
          load = 0;
          break;                               // drop out of input routine and process the command request
        }
        if (pointer == 0) {
          Serial.println(PROMPT);
          zero = 0;
          load = 0;
          saved = 0;
          continue;                            // we reset and go back to collect another line of input from serial
        }
        if ((activated == 0) and (pointer > 0)) {
          Serial.println("ignoring command because loader is not activated");
          saved = 0;
          pointer = 0;
          zero = 0;
          load = 0;
          Serial.println(PROMPT);
          continue;                            // we reset and go back to collect another line of input from serial
        } else if ((pointer > 0) and (pointer != 4)) {
          Serial.print("dropping partial word or extraneous characters ");
          for (int i = 0; i <= pointer; i++) {
            Serial.write(newword[i]);
          }
          zero = 0;
          Serial.println("");
        }
        if (pointer == 4) {
          pointer = 0;
          break;                               // drop out input routine and process the command request
        }
        Serial.println(PROMPT);
        pointer = 0;
        load = 0;
        continue;                                 // end input loop and go execute
      }
      // turn on flags when we encounter the command characters
      if (incomingchar == ACTIVATECHAR) {      // request to activate or deactivate our control over the 1130
        if (activated == 1) {
          deact = 1;
          act = 0;
        } else {
          act = 1;
          deact = 0;
        }
        continue;                              // mark command and continue collecting the four characters
      }

      if (incomingchar == ZEROCHAR) {          // store NNNN words of zero in memory
        zero = 1;
        continue;                              // mark command and continue collecting the four characters
      }
      if (incomingchar == LOADCHAR) {          // load the IAR with value AAAA
        load = 1;
        continue;                              // mark command and continue collecting the four characters
      }
      if (incomingchar == STARTCHAR) {         // save the start address AAAA of this code
        saved = 1;
        continue;                              // mark command and continue collecting the four characters
      }

      // accumulate characters up to count of four then act on it if we are activated
      if ((act == 1) or (deact == 1)) {
         Serial.print("Activate character must be on a line of its own, ignoring ");
         Serial.write(incomingchar);
         Serial.println("");
         continue;                             // didn't save char, go back to read input
      }
      if ((incomingchar == ' ') and (pointer == 0)) {
        continue;
      }
      if (pointer < 4) {
        newword[pointer] = incomingchar;
      }
      pointer++;
      if (pointer > 4) {
        Serial.print("ignoring excess character ");
        Serial.write(incomingchar);
        Serial.println("");
      }
      if (pointer == 4) {
        if (activated == 0) {
          Serial.print("IBM 1130 Loader is waiting for activation\nPress Imm Stop to be certain system is stopped.\n");
          Serial.println("# is command to activate the loader.\n");
          saved = 0;
          pointer = 0;
          zero = 0;
          load = 0;
          continue;                            // we reset and go back to collect another line of input from serial
        } 
        if (checkword(newword)) {       // verify that XXXX is valid hexadecimal
          if (zero == 1) {                     // document request to zero out 0xNNNN words from this point onward
            times = (int)strtol(newword, NULL, 16);
            if (times < 1) {
              Serial.println("number of words to zero must range from 1 to 32,767");
              times = 1;
              zero = 0;
              pointer = 0;
              load = 0;
              Serial.println(PROMPT);
              continue;                        // we reset and go back to collect another line of input from serial
            }
          } else if (saved == 1) {             // document we are saving the start IAR of this file
            saved = 0;
            Serial.print("When done loading, start executing this code at "); Serial.println(newword);
            saveaddr[0] = newword[0];
            saveaddr[1] = newword[1];
            saveaddr[2] = newword[2];
            saveaddr[3] = newword[3];            
            pointer = 0;
            load = 0;
            continue;                           // we reset and go back to collect another line of input from serial
          }
          continue;                             // go back to finish collecting line
        } else {
        Serial.println("not a valid hex word, dropped");
        pointer = 0;
        Serial.println(PROMPT);
        continue;                               // we reset and go back to collect another line of input from serial
        }
      }
    }
  }

  // execution section of the loop, once we collected a command request and a hex data value

  // first see if we need to deactivate control of the 1130
  if (deact == 1) {                             // we shut down the control over the 1130

    // do we have a saved start address? If so, set IAR to that value
    if (saveaddr[0] != 0)  {
      Serial.print("we had a saved address, please load IAR with ");
      Serial.print((int)strtol(saveaddr, NULL, 16), HEX);
      Serial.println(" then hit Prog Start button to execute");
    }

    // proceed with deactivation
    Serial.println("Deactivated - use 1130 as you wish");
    deact = 0;
    activated = 0;
    saveaddr[0] = 0;
    currentaddress = 0;
  }
    
  // we have a valid word, lets load into the 1130 if we are activated
  if (activated == 1) {
        returnvalue = grabvalue(newword);      // don't turn on any CES if storing zeroes
      if (zero == 1) {
        Serial.print("zeroing out ");
        Serial.print(times);
        Serial.print(" (hex ");
        Serial.print(times,HEX);
        Serial.println(") consecutive words");
        returnvalue = 0;
      }
      for (int i = 1; i <= times; i++) {
        if (load == 1) {                        // change the current address to the value from the command line
          Serial.print("next store at "); Serial.println(newword);
          currentaddress = returnvalue;
          load = 0;
        } else {                               // grab the value from the command line and ask the shield to put it in memory
          if (zero == 0) {
            Serial.print(newword);
            Serial.print(" @"); Serial.println(currentaddress, HEX);
          }
          outputdata = returnvalue;
          store2memory();
          currentaddress++;                     // bump the core address to the next sequential location
        }
      }
      zero = 0;
      times = 1;
  }

  // lastly lets see if we need to activate control of the 1130
  if (act == 1) {
    Serial.println("Activated");
    activated = 1;
    saveaddr[0] = 0;
    act = 0;
    currentaddress = 0;              // default core address of 0000 until changed by @ command
  }

}

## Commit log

2023-11-15 Version 2 of Arduino code
2023-11-15 First upload of V2 shield PCB layout (KiCAD)
    [newloader.kicad_pcb]
2023-11-15 Schematic of V2 shield (KiCAD)
    [newloader.kicad_sch]
2023-11-15 Gerber files for V2 shield PCB
2023-11-16 Fixed issue when USB and +12V both power the Arduino
2023-11-16 Changed PCB to fix multiple powering issue
    [newloader.kicad_pcb]
2023-11-19 updating PCB
    [newloader.kicad_pcb]
2023-11-19 updating schematic
    [newloader.kicad_sch]
2023-11-19 updating PCB gerbers
2023-11-19 Updated corrected V2 design
    [newloader.kicad_pcb, newloader.kicad_sch]
2023-11-19 Gerbers and drills related to corrected V2 design
2023-12-05 V3 for easier parts purchase of 16 pin header
    [newloader.kicad_pcb, newloader.kicad_sch]
2023-12-05 V3 for easier parts purchase for 16 pin header
2023-12-05 removed V2 of pcb
2024-03-05 updated to avoid wiring error in 1130
2024-03-12 V4 with alternate wiring to 1130
    Prior wiring method allowed bounce to show up as multiple button presses. New method solves that issue.
    [newloader.kicad_pcb, newloader.kicad_sch]
2024-03-12 V4 describing new wiring to 1130
2024-03-12 Newest PCB gerber and drill files for V4
2024-03-12 V4 of code to match other files
    New PCB alters design, new wiring method from the loader to the IBM 1130 and improved code
2024-03-12 Explanation for mounting the loader
2024-03-12 project now complete with upload of mounting document
2024-03-15 Remove superfluous message to terminal
    when the loader skips leading spaces on command lines, it issued a comment that this had taken place. This is unnecessary and clogs the terminal session. removed the println
2024-03-15 Added information on powering the Arduino
    Made the power connections to the Arduino clearer
2024-05-26 Alert builders of new version coming using DMA
2024-09-26 Update README.md
    DMA/Cycle Steal loader tested and working well
